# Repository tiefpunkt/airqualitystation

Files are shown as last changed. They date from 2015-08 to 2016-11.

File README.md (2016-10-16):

# Air Quality Station

Small outdoor particulate matter sensor. Measures PM1.0 and PM2.5, as well as temperature and humidity. Connects to an online service to show the measurements not only of one sensor, but all sensors in the area.

## Hardware
* ESP8266
* [Custom PCB](hardware/) (or your own whatever thingie)
* A bunch of small parts (TODO: Add BOM)
* DHT22 for temperature and humidity ([Grove Wiki](http://www.seeedstudio.com/wiki/Grove_-_Temperature_and_Humidity_Sensor_Pro))
* Shinyei PPD42NS for PM2.5 and PM1.0 ([Grove Wiki](http://www.seeedstudio.com/wiki/Grove_-_Dust_Sensor))

## Setup
* Solder up the PCB (PCBs might be for sale in the future, in the meantime look at the files [here](hardware/))
* Crimp the sensors to the connectors
* Put your WiFi credentials in the firmware
* Flash the firmware via the FTDI connector on the board (make sure it's set to 3.3V)
* Connect the sensors
* Put it all in a weatherproof box, that let's air in.
* Place it outside
* Power it up

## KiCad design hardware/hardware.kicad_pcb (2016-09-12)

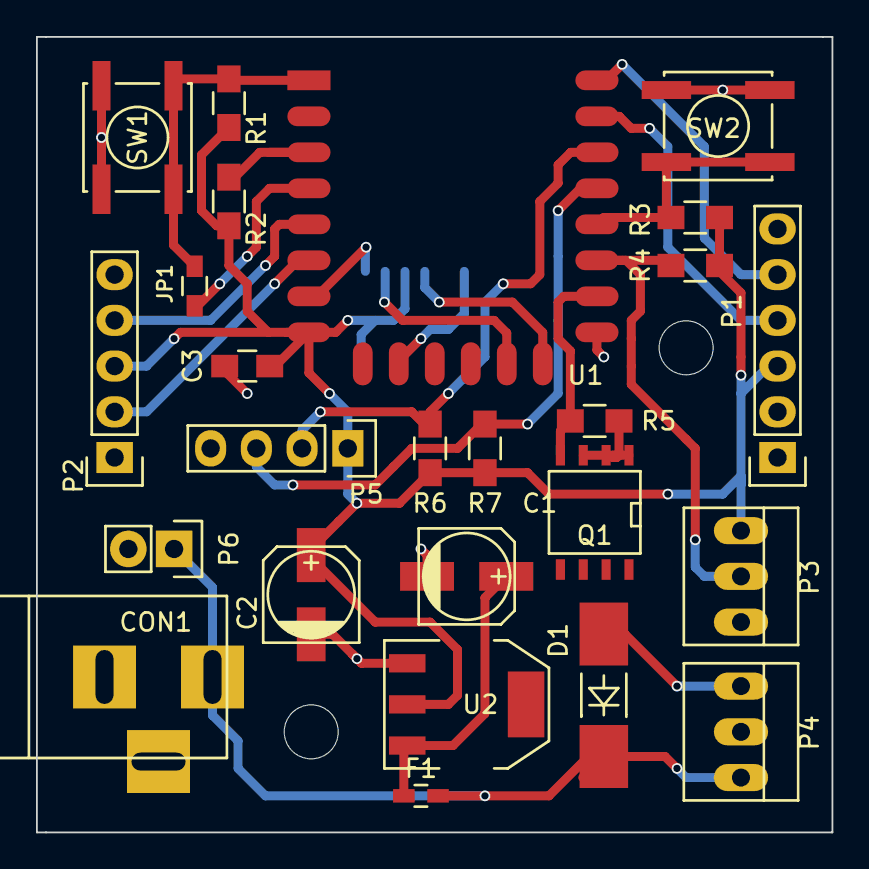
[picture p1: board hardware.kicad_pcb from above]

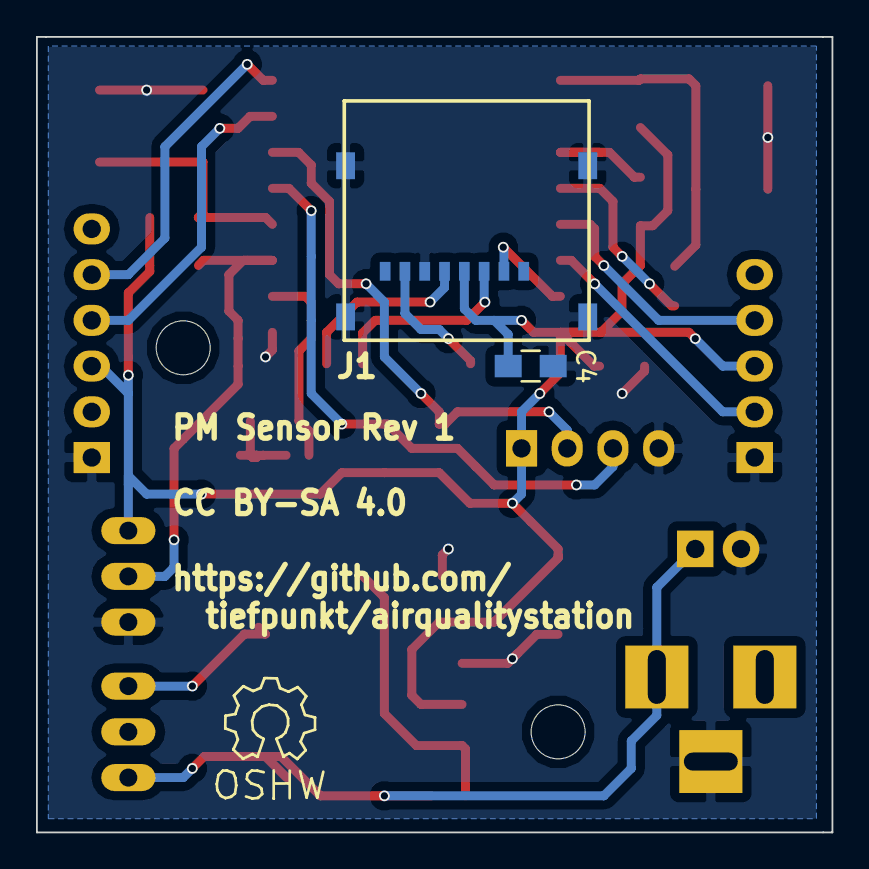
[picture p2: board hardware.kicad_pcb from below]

Board: 2 copper layers, 44.2 x 44.2 mm, 27 parts (2 on the bottom side), 21 nets.

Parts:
C1, C2: 10µ; c_elec_5x5.3
C3, C4: 100n; C_0805_HandSoldering
CON1: Power; BARREL_JACK
D1: D; MELF_Handsoldering
F1: 0.1A; C_0603_HandSoldering
J1: MicroSD; MICRO_SD_HINGE_AMP
JP1: Sleep; R_0603_HandSoldering
P1: FTDI ESP; Pin_Header_Straight_1x06
P2: PPD42NS; Pin_Header_Straight_1x05
P3: DHT22; PINHEAD1-3
P4: Fan; PINHEAD1-3
P5: I2C; Pin_Header_Straight_1x04
P6: 5-9V; Pin_Header_Straight_1x02
Q1: IRF7401; SOIC-8-N
R1, R2, R3, R4, R5, R6, R7: 10k; R_0805_HandSoldering
SW1: Reset; SW_SPST_EVPBF
SW2: Flash; SW_SPST_EVPBF
U1: ESP-12E
U2: TS 1117 BCW33; SOT-223

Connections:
+9V: CON1.1, D1.1, F1.1, P4.3, P6.1
GND: C1.2, C2.2, C3.2, C4.2, CON1.3, J1.6, J1.SHLD, P1.1, P2.1, P3.3, P5.4, P6.2, Q1.1, Q1.2, Q1.3, R5.2, SW1.2, SW2.2, U1.15, U2.1
unnamed: C1.1, F1.2, U2.3
unnamed: D1.2, P4.1, Q1.5, Q1.6, Q1.7
unnamed: J1.2, U1.7
unnamed: J1.3, U1.13
unnamed: J1.5, U1.14
unnamed: J1.7, U1.10
unnamed: JP1.1, U1.4
unnamed: JP1.2, R1.2, SW1.1, U1.1
unnamed: P1.4, U1.21
unnamed: P1.5, U1.22
unnamed: P2.2, U1.6
unnamed: P2.4, U1.5
unnamed: P3.2, R4.2, U1.17
unnamed: P5.2, R6.2, U1.20
unnamed: P5.3, R7.2, U1.19
unnamed: Q1.4, R5.1, U1.16
unnamed: R2.2, U1.3
unnamed: R3.2, SW2.1, U1.18
VCC: C2.1, C3.1, C4.1, J1.4, P1.3, P2.3, P3.1, P5.1, R1.1, R2.1, R3.1, R4.1, R6.1, R7.1, U1.8, U2.2

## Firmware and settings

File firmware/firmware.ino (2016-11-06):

/************************************************************/
/* OK LAB Particulate Matter Sensor                         */
/*      - nodemcu-LoLin board                               */
/*      - Shinyei PPD42NS                                   */
/*      http://www.sca-shinyei.com/pdf/PPD42NS.pdf          */
/*                                                          */
/* Wiring Instruction:                                      */
/*      Pin 2 of dust sensor PM2.5 -> Digital 6 (PWM)       */
/*      Pin 3 of dust sensor       -> +5V                   */
/*      Pin 4 of dust sensor PM1   -> Digital 3 (PMW)       */
/*                                                          */
/*      - PPD42NS Pin 1 (grey or green)  => GND             */
/*      - PPD42NS Pin 2 (green or white)) => Pin D5 /GPIO14 */
/*        counts particles PM25                             */
/*      - PPD42NS Pin 3 (black or yellow) => Vin            */
/*      - PPD42NS Pin 4 (white or black) => Pin D6 / GPIO12 */
/*        counts particles PM10                             */
/*      - PPD42NS Pin 5 (red)   => unused                   */
/*                                                          */
/************************************************************/

// increment on change
#define SOFTWARE_VERSION "20160908_01"

#include "config.h"

/**********************************************/
/* DHT declaration
/**********************************************/
#include <DHT.h>
#define DHTPIN 2
#define DHTTYPE DHT22
DHT dht(DHTPIN, DHTTYPE, 25);
String dht_data;

/**********************************************/
/* WiFi declarations
/**********************************************/
#include <ESP8266WiFi.h>
#include <ESP8266WiFiMulti.h>

ESP8266WiFiMulti wifiMulti;

long start_of_operation = 0;
/**********************************************/
/* The Setup
/**********************************************/
void setup() {
  Serial.begin(9600); //Output to Serial at 9600 baud
  delay(10);

  // Mac address
  WiFi.macAddress(mac);
  byteToHexString(strMac, mac, 6, ":");
  byteToHexString(strDeviceId, mac, 6, "");

  Serial.println("## Particulate Matter Sensor ##");
  Serial.print("Software version: ");
  Serial.println(SOFTWARE_VERSION);
  Serial.print("Device Identifier (MAC): ");
  Serial.println(strMac);

  WIFI_MULTI_APS

  connectWifi(); // Start ConnecWifi

  dht.begin(); // Start DHT
  initDustsensor();

  start_of_operation = millis();
}

/**********************************************/
/* And action
/**********************************************/
void loop() {
  if (readDustsensor()) {
    // FIXME: option to send PIN
    sensorDHT();  // getting temperature and humidity (optional)

    if(wifiMulti.run() != WL_CONNECTED) {
        connectWifi();
    }

    if (millis()-start_of_operation > WARMUP_PERIOD) {
      sendData();
    } else {
      Serial.println("Warmup period, not sending data yet");
    }
    //sensorBarometer();
    Serial.println("------------------------------");
  }
}
// DHT22 Sensor
void sensorDHT(){
 float h = dht.readHumidity(); //Read Humidity
 float t = dht.readTemperature(); //Read Temperature
 // Check if valid number if non NaN (not a number) will be send.
 if (isnan(t) || isnan(h)) {
   Serial.println("DHT22 couldn’t be read");
 } else {
   Serial.print("Humidity    : ");
   Serial.print(h);
   Serial.print(" %\n");
   Serial.print("Temperature : ");
   Serial.print(t);
   Serial.println(" C");
   dht_data= "{\"temperature\":\"";
   dht_data += Float2String(t);
   dht_data += "\", \"humidity\":\"";
   dht_data += Float2String(h);
   dht_data += "\"}";
 }
}

String getDHTData() {
  return dht_data;
}
/*
void sensorBarometer() {
  String data;
  temperature = myBarometer.bmp085GetTemperature(myBarometer.bmp085ReadUT()); //Get the temperature, bmp085ReadUT MUST be called first
  pressure = myBarometer.bmp085GetPressure(myBarometer.bmp085ReadUP());//Get the temperature
  altitude = myBarometer.calcAltitude(pressure); //Uncompensated caculation - in Meters

  Serial.print("Temperature: ");
  Serial.print(temperature, 2); //display 2 decimal places
  Serial.println("deg C");

  Serial.print("Pressure: ");
  Serial.print(pressure, 0); //whole number only.
  Serial.println(" Pa");

  Serial.print("Altitude: ");
  Serial.print(altitude, 2); //display 2 decimal places
  Serial.println(" m");

   data= "{\"temperature\":\"";
   data += Float2String(temperature);
   data += "\", \"pressure\":\"";
   data += Float2String(pressure);
   data += "\", \"altitude\":\"";
   data += Float2String(altitude);
   data += "\"}";
}

*/
/**********************************************/
/* WiFi connecting script
/**********************************************/
void connectWifi() {
  WiFi.mode(WIFI_STA);
  Serial.print("Connecting ");
  while (wifiMulti.run() != WL_CONNECTED)
  {
    delay(500);
    Serial.print(".");
  }
  Serial.printf("WiFi connected to %s\n", WiFi.SSID().c_str());
  Serial.print("IP address: ");
  Serial.println(WiFi.localIP());
  Serial.printf(" connected to %s\n", WiFi.SSID().c_str());
}

void byteToHexString(String &dataString, byte *uidBuffer, byte bufferSize, String strSeperator) {
  dataString = "";
  for (byte i = 0; i < bufferSize; i++) {
    if (i>0) {
      dataString += strSeperator;
      if (uidBuffer[i] < 0x10)
        dataString += String("0");
    }
    dataString += String(uidBuffer[i], HEX);
  }
  dataString.toUpperCase();
}

String Float2String(float value) {
  // Convert a float to String with two decimals.
  char temp[15];
  String s;

  dtostrf(value,13, 2, temp);
  s = String(temp);
  s.trim();
  return s;
}

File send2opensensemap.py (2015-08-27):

#!/bin/python
import serial
import json
import requests

import config

ser = serial.Serial(config.SERIAL, 9600, timeout=10)

def sendMeasurement(id, value):
	# http://opensensemap.org:8000/boxes/boxId/sensorId
	url = "http://opensensemap.org:8000/boxes/%s/%s" % (config.SENSEBOX_ID, id)
	data = { "value" : value }
	headers = {'Content-type': 'application/json', 'Accept': 'text/plain'}
	# print url
	try:
		r = requests.post(url, data=json.dumps(data), headers=headers, timeout = 2)
	except:
		print "error making request"
		return
	#print r.status_code
	print r.content
	#print

while True:
	line = ser.readline()
	try:
		data = json.loads(line)
	except ValueError:
		continue

	for key, value in data.iteritems():
		if key == "temperature":
			sendMeasurement(config.TEMPERATURESENSOR_ID, value)
		elif key == "pressure":
			sendMeasurement(config.PRESSURESENSOR_ID, value)
		elif key == "humidity":
			sendMeasurement(config.HUMIDITY_ID, value)
		elif key == "pm25":
			sendMeasurement(config.PM_ID, value)
		elif key == "uv_intensity":
			sendMeasurement(config.UVINTENSITY_ID, value)
		elif key == "uv_index":
			sendMeasurement(config.UVINDEX_ID, value)

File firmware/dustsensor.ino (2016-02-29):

/**********************************************/
/* Variable Definitions for PPD24NS
/**********************************************/
// P1 for PM10 & P2 for PM25
unsigned long sampletime_ms = 30000;
unsigned long lowpulseoccupancyP1 = 0;
unsigned long lowpulseoccupancyP2 = 0;
unsigned long lowpulseoccupancyP1_old = 0;
unsigned long lowpulseoccupancyP2_old = 0;
unsigned long sampletime_ms_actual = 0;

float ratioP1 = 0;
float concentrationP1 = 0;
float ratioP2 = 0;
float concentrationP2 = 0;
boolean valP1 = HIGH;
boolean valP2 = HIGH;

unsigned long starttime;
unsigned long durationP1;
unsigned long durationP2;

boolean trigP1 = false;
boolean trigP2 = false;
unsigned long trigOnP1;
unsigned long trigOnP2;

// Slowly moving average
#define  numberOfPeaksRecording              5
uint32_t    previousPeaksP1[numberOfPeaksRecording];
uint32_t    previousPeaksP2[numberOfPeaksRecording];
uint32_t    slowMovingAverageP1       = 0;
uint32_t    slowMovingAverageP2       = 0;
uint32_t    sumOfPreviousPeaks     = 0;
uint32_t    instantGoal             = 0;
int32_t     delta                   = 0;

void initDustsensor() {
  pinMode(12,INPUT); // Listen at the designated PIN
  pinMode(14,INPUT); //Listen at the designated PIN
  starttime = millis(); // store the start time
}

boolean readDustsensor() {
  // Read pins connected to ppd42ns
  valP1 = digitalRead(12);
  valP2 = digitalRead(14);

  if(valP1 == LOW && trigP1 == false){
    trigP1 = true;
    trigOnP1 = micros();
  }
  
  if (valP1 == HIGH && trigP1 == true){
    durationP1 = micros() - trigOnP1;
    lowpulseoccupancyP1 = lowpulseoccupancyP1 + durationP1;
    trigP1 = false;
  }
  
  if(valP2 == LOW && trigP2 == false){
    trigP2 = true;
    trigOnP2 = micros();
  }
  
  if (valP2 == HIGH && trigP2 == true){
    durationP2 = micros() - trigOnP2;
    lowpulseoccupancyP2 = lowpulseoccupancyP2 + durationP2;
    trigP2 = false;
  }

  // Checking if it is time to sample
  if ((millis()-starttime) > sampletime_ms) {
    sampletime_ms_actual = millis()-starttime;
    ratioP1 = lowpulseoccupancyP1/(sampletime_ms_actual*10.0);                 // int percentage 0 to 100
    concentrationP1 = 1.1*pow(ratioP1,3)-3.8*pow(ratioP1,2)+520*ratioP1+0.62; // spec sheet curve

    // Begin printing
    Serial.print("LPO P10     : ");
    Serial.println(lowpulseoccupancyP1);
    Serial.print("Ratio PM10  : ");
    Serial.print(ratioP1);
    Serial.println(" %");
    Serial.print("PM10 Count  : ");
    Serial.println(concentrationP1);
    
    ratioP2 = lowpulseoccupancyP2/(sampletime_ms_actual*10.0);
    concentrationP2 = 1.1*pow(ratioP2,3)-3.8*pow(ratioP2,2)+520*ratioP2+0.62;
    // Begin printing
    Serial.print("LPO PM25    : ");
    Serial.println(lowpulseoccupancyP2);
    Serial.print("Ratio PM25  : ");
    Serial.print(ratioP2);
    Serial.println(" %");
    Serial.print("PM25 Count  : ");
    Serial.println(concentrationP2);

    // shift counters over, code adapted from template provided by Mike Taylor and Joshua Schapiro from Carnegie Mellon University's CREATE Lab
    for (uint8_t i = 0; i < (numberOfPeaksRecording-1); i++) {
        previousPeaksP1[i] = previousPeaksP1[i+1];
        previousPeaksP2[i] = previousPeaksP2[i+1];
    }
    previousPeaksP1[numberOfPeaksRecording - 1] = concentrationP1;
    previousPeaksP2[numberOfPeaksRecording - 1] = concentrationP2;

    slowMovingAverageP1 = recalcSlowMovingAverage(previousPeaksP1, slowMovingAverageP1);
    slowMovingAverageP2 = recalcSlowMovingAverage(previousPeaksP2, slowMovingAverageP2);

    Serial.print("PM10 Average  : ");
    Serial.println(slowMovingAverageP1);
    Serial.print("PM25 Average  : ");
    Serial.println(slowMovingAverageP2);

    // Resetting for next sampling
    lowpulseoccupancyP1_old = lowpulseoccupancyP1;
    lowpulseoccupancyP2_old = lowpulseoccupancyP2;
    lowpulseoccupancyP1 = 0;
    lowpulseoccupancyP2 = 0;
    trigP1 = false;
    trigP2 = false;
    starttime = millis(); // store the start time
    
    return true;
  }
  return false;
}

uint32_t recalcSlowMovingAverage(uint32_t previousPeaks[], uint32_t slowMovingAverage) {
  sumOfPreviousPeaks = 0;
  
  for (uint8_t i = 0; i < numberOfPeaksRecording; i++) {
      sumOfPreviousPeaks += previousPeaks[i];
  }
  instantGoal = 2*sumOfPreviousPeaks;

  delta = instantGoal - slowMovingAverage;

  if (delta < -5000){
      slowMovingAverage = slowMovingAverage - 250;
  } else if (delta < -2500){
      slowMovingAverage = slowMovingAverage - 120;
  } else if(delta < -1200){
      slowMovingAverage = slowMovingAverage - 60;
  } else if(delta < -500){
      slowMovingAverage = slowMovingAverage - 25;
  } else if(delta < -5){
      slowMovingAverage = slowMovingAverage - 5;
  } else if(delta < -1){
      slowMovingAverage = slowMovingAverage - 1;
  } else if(delta > 5000) {
      slowMovingAverage = slowMovingAverage + 500;
  } else if(delta > 2500){
      slowMovingAverage = slowMovingAverage + 250;
  } else if(delta > 1200){
      slowMovingAverage = slowMovingAverage + 120;
  } else if(delta > 500){
      slowMovingAverage = slowMovingAverage + 50;
  } else if(delta > 5){
      slowMovingAverage = slowMovingAverage + 5;
  } else if(delta > 1){
      slowMovingAverage = slowMovingAverage + 1;
  }

  return slowMovingAverage;
}

String getDustData() {
  String data;
  data = "{\"P1\":{";
    //data += "\"lowpulseoccupancy\":\"";
    //data += long(lowpulseoccupancyP1_old);
    //data += "\",";
    //data += "\"ratio\":\"";
    //data += Float2String(ratioP1);
    //data += "\",";
    data += "\"concentration\":\"";
    data += Float2String(concentrationP1);
    data += "\",";
    data += "\"concentration_avg\":\"";
    data += Float2String(slowMovingAverageP1);
    data += "\"},\"P2\":{";
    //data += "\"lowpulseoccupancy\":\"";
    //data += long(lowpulseoccupancyP2_old);
    //data += "\",";
    //data += "\"ratio\":\"";
    //data += Float2String(ratioP2);
    //data += "\",";
    data += "\"concentration\":\"";
    data += Float2String(concentrationP2);
    data += "\",";
    data += "\"concentration_avg\":\"";
    data += Float2String(slowMovingAverageP2);
    data += "\"},\"sampletime\":\"";
    data += long(sampletime_ms_actual);
    data += "\"}";
    return data;
}

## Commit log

2016-02-29 Firmware rewrite for ESP8266, using HTTP instead of MQTT
    Unit will only post to server, no need for messaging at the moment.
    Thus, it makes no sense to keep up an MQTT connection.
    HTTP/HTTPS will have to suffice. Using HTTP for now, should be
    an easy switch to HTTPS though.
2016-08-10 schematic and pcb
    [hardware.kicad_pcb, hardware.sch]
2016-09-12 pcb of the first production run
    [hardware.kicad_pcb, hardware.sch]
2016-11-06 - reactivated warum period after testing - changed DEBUG_PRINTLN to Serial.print to get MAC printed correctly at startup
    [firmware.ino]

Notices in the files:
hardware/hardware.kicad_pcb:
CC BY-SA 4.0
